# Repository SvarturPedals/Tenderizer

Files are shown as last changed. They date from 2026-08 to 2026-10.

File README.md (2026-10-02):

Tenderizer is a recreation of the Gristleizer Eurorack Module once produced by Endangered Audio Research.

-----------------------------------------------------------------------------------------------------------------------------

V1 prototype boards were ordered on 9-9-26. 

Tests were positive, but revealed a couple of small errors.

See links for testing and demo of V1 prototype:

https://www.youtube.com/watch?v=e3SwFMtvKbs

https://www.youtube.com/watch?v=fW0amLK4cTc

V2 prototypes ordered on 9-22-26 which included a prototype PCB material front panel.

V2 prototypes arrived on 9-29-26, Built and tested first unit with good results. 

Will distribute 3 board sets to select people to build and test during the months of October, November and December of 2026. 

Any issues found will be addressed in V3 Final version.

PXL_20260930_220714235~3PXL_20260930_211127180~2

10-1-26:

Updated Repository with BOM files. 

Excel and Open Office Calc files are identical

Markdown Table format

HTML format (https://html-preview.github.io/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)

-----------------------------------------------------------------------------------------------------------------------------

Current back of the envelope math for future Board Sets, Complete Kits, and a limited number of completed and tested modules

Board Sets : $25 USD

Complete kits : $85 USD

Built and Tested units with special front panels : $225 USD

Pricing subject to change, more details once launched.

I will set up an Etsy store front for the official launch.

Potential Launch date:

January 1, 2027

Once launched, all PCB fabrication files will be uploaded here along with a full build documentation and other project specific notes.

-----------------------------------------------------------------------------------------------------------------------------

Original Assembly document for E.A.R. Gristleizer Eurorack PCB

https://drive.google.com/file/d/1BdbNv-EVg8JeGNcPxPTs-spx8XBo5OCM/view?usp=sharing

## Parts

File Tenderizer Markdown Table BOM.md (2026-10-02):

| Components | Quantity | Value | Notes |
|---|---|---|---|
| Resistors | | | |
| R4 | 1 | 22R | 1/4w Metal Film Resistor 1% 2.5mmx6.8mm |
| R6,R11,R18,R32,R35 | 5 | 1K | 1/4w Metal Film Resistor 1% 2.5mmx6.8mm |
| R36 | 1 | 2.2K | 1/4w Metal Film Resistor 1% 2.5mmx6.8mm |
| R8 | 1 | 4.7K | 1/4w Metal Film Resistor 1% 2.5mmx6.8mm |
| R9,R14,R19,R24,R27,R31 | 6 | 10K | 1/4w Metal Film Resistor 1% 2.5mmx6.8mm |
| R13,R25 | 2 | 18K | 1/4w Metal Film Resistor 1% 2.5mmx6.8mm |
| R7 | 1 | 22K | 1/4w Metal Film Resistor 1% 2.5mmx6.8mm |
| R10,R26 | 2 | 27K | 1/4w Metal Film Resistor 1% 2.5mmx6.8mm |
| R16,R28 | 2 | 33K | 1/4w Metal Film Resistor 1% 2.5mmx6.8mm |
| R5,R34,R39 | 3 | 47K | 1/4w Metal Film Resistor 1% 2.5mmx6.8mm |
| R3,R33 | 2 | 56K | 1/4w Metal Film Resistor 1% 2.5mmx6.8mm |
| R22 | 1 | 82K | 1/4w Metal Film Resistor 1% 2.5mmx6.8mm |
| R15,R17,R20,R21 | 4 | 100K | 1/4w Metal Film Resistor 1% 2.5mmx6.8mm |
| R29 | 1 | 180K | 1/4w Metal Film Resistor 1% 2.5mmx6.8mm |
| R30 | 1 | 470K | 1/4w Metal Film Resistor 1% 2.5mmx6.8mm |
| R2,R12 | 2 | 1M | 1/4w Metal Film Resistor 1% 2.5mmx6.8mm |
| | | | |
| Capacitors | | | |
| C8 | 1 | 2.2nf | Polyester Box Film Body 2.5mm (minimum 25v DC Voltage Rating) |
| C7,C14 | 2 | 10nf | Polyester Box Film Body 2.5mm (minimum 25v DC Voltage Rating) |
| C2,C3 | 2 | 100nf | Polyester Box Film Body 2.5mm (minimum 25v DC Voltage Rating) |
| C1 | 1 | 470nf | Polyester Box Film Body 3.5mm (minimum 25v DC Voltage Rating) |
| C4 | 1 | 1uf | Aluminum Electrolytic 5mm diameter (minimum 25v DC Voltage Rating) |
| C5,C9 | 2 | 10uf | Aluminum Electrolytic 5mm diameter (minimum 25v DC Voltage Rating) |
| C11,C12 | 2 | 100uf | Aluminum Electrolytic 6.3mm diameter (minimum 25v DC Voltage Rating) |
| | | | |
| Diodes | | | |
| D2 | 1 | 1N4738  | Zener Diode |
| D3,D4 | 2 | 1N4148  | Switching Signal Diode |
| D6,D7 | 2 | 1N5817  | Diode Schottky |
| D9 | 1 | 5mm LED | Red Diffused or color of your choice |
| | | | |
| Transistors | | | |
| Q1 | 1 | BF256 | Board sets and Kits ordered from Svartur Effects will include this part |
| Q3,Q4 | 2 | 2N3906  | |
| | | | |
| Integrated Circuits | | | |
| U1,U2,U3 | 3 | RC4558  | DIP Package |
| | | | |
| Other | | | |
| DPDT On/On toggle switch | 2 | | |
| Bias, Depth, Level, Gain, Filter | 5 | B100k | |
| Frequency | 1 | A10k | |
| 3.5mm jacks | 10 | | Thonk PJ301-M Style |
| 1x16 2.54mm Male Pin Connector | 1 | | |
| 1x16 2.54mm Female Pin Connector | 1 | | |
| 1x8 2.54mm Male Pin Connector | 1 | | |
| 1x8 Female Pin Connector | 1 | | |
| 2x5 Eurorack Power Connector | 1 | | |
| 8 Pin IC Socket | 3 | | |
| 3 Pin Transistor Socket (Optional) | 3 | | |

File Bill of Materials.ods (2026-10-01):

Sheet: Master BOM List
Components | Quantity | Value | Notes
Resistors
R4 | 1 | 22R | 1/4w Metal Film Resistor 1% 2.5mmx6.8mm
R6,R11,R18,R32,R35 | 5 | 1K | 1/4w Metal Film Resistor 1% 2.5mmx6.8mm
R36 | 1 | 2.2K | 1/4w Metal Film Resistor 1% 2.5mmx6.8mm
R8 | 1 | 4.7K | 1/4w Metal Film Resistor 1% 2.5mmx6.8mm
R9,R14,R19,R24,R27,R31 | 6 | 10K | 1/4w Metal Film Resistor 1% 2.5mmx6.8mm
R13,R25 | 2 | 18K | 1/4w Metal Film Resistor 1% 2.5mmx6.8mm
R7 | 1 | 22K | 1/4w Metal Film Resistor 1% 2.5mmx6.8mm
R10,R26 | 2 | 27K | 1/4w Metal Film Resistor 1% 2.5mmx6.8mm
R16,R28 | 2 | 33K | 1/4w Metal Film Resistor 1% 2.5mmx6.8mm
R5,R34,R39 | 3 | 47K | 1/4w Metal Film Resistor 1% 2.5mmx6.8mm
R3,R33 | 2 | 56K | 1/4w Metal Film Resistor 1% 2.5mmx6.8mm
R22 | 1 | 82K | 1/4w Metal Film Resistor 1% 2.5mmx6.8mm
R15,R17,R20,R21 | 4 | 100K | 1/4w Metal Film Resistor 1% 2.5mmx6.8mm
R29 | 1 | 180K | 1/4w Metal Film Resistor 1% 2.5mmx6.8mm
R30 | 1 | 470K | 1/4w Metal Film Resistor 1% 2.5mmx6.8mm
R2,R12 | 2 | 1M | 1/4w Metal Film Resistor 1% 2.5mmx6.8mm
Capacitors
C8 | 1 | 2.2nf | Polyester Box Film 5mm Lead Spacing Body Thickness 2.5mm (minimum 25v DC Voltage Rating)
C7,C14 | 2 | 10nf | Polyester Box Film 5mm Lead Spacing Body Thickness 2.5mm (minimum 25v DC Voltage Rating)
C2,C3 | 2 | 100nf | Polyester Box Film 5mm Lead Spacing Body Thickness 2.5mm (minimum 25v DC Voltage Rating)
C1 | 1 | 470nf | Polyester Box Film 5mm Lead Spacing Body Thickness 3.5mm (minimum 25v DC Voltage Rating)
C4 | 1 | 1uf | Aluminum Electrolytic 5mm diameter (minimum 25v DC Voltage Rating)
C5,C9 | 2 | 10uf | Aluminum Electrolytic 5mm diameter (minimum 25v DC Voltage Rating)
C11,C12 | 2 | 100uf | Aluminum Electrolytic 5mm diameter (minimum 25v DC Voltage Rating)
Diodes
D2 | 1 | 1N4738 | ZENER DIODE 1W 8.2V
D3,D4 | 2 | 1N4148 | Switching Signal Diode
D6,D7 | 2 | 1N5817 | Diode Schottky 1A 20V
D9 | 1 | 5mm LED | Red Diffused or color of your choice
Transistors
Q1 | 1 | BF256 | TO-92 Package (Board sets ordered from Svartur Effects will include this part)
Q3,Q4 | 2 | 2N3906 | TO-92 Package
Integrated Circuits
U1,U2,U3 | 3 | RC4558 | DIP Package
Other
DPDT On/On toggle switch | 2
Bias, Depth, Level, Gain, Filter | 5 | B100k
Frequency | 1 | A10k
3.5mm jacks | 10 |  | Thonk PJ301-M Style
1x16 2.54mm Male Pin Connector | 1 |  | Just get a few strips of the 40 pin breakable headers at the link ---->
1x16 2.54mm Female Pin Connector | 1
1x8 2.54mm Male Pin Connector | 1 |  | Just get a few strips of the 40 pin breakable headers at the link ---->
1x8 Female Pin Connector | 1
2x5 Eurorack Power Connector | 1
8 Pin IC Socket | 3
3 Pin Transistor Socket (Optional) | 3

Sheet: US Domestic Ordering
Components | Quantity | Value | Mouser Part Number | Quantity | Supplier Links
Resistors
R4 | 1 | 22R | 660-MF1/4LCT52R220J 1 | Mouser BOM Order Tool
R6,R11,R18,R32,R35 | 5 | 1K | 660-MF1/4LCT52R102J 5 | For quick entry, log in to you Mouser Account and navigate to the BOM tool at https://www.mouser.com/en/account/boms
R36 | 1 | 2.2K | 660-MF1/4LCT52R222G 1 | Select “Create New BOM” then “Copy and Paste”
R8 | 1 | 4.7K | 660-MF1/4LCT52R472J 1 | In this Spreadsheet, select Cell D3, hold Shift, then select Cell D53. With Cells D3 through D53 highlighted, right click and select “Copy” or hit Ctrl C
R9,R14,R19,R24,R27,R31 | 6 | 10K | 660-MF1/4DCT52R1002F 6 | Paste that list into the BOM window on Mouser then select “Import My Data”
R13,R25 | 2 | 18K | 660-MF1/4DCT52R1802F 2 | Once the BOM is successfully imported, select Next and then “Process BOM”
R7 | 1 | 22K | 660-MF1/4DCT52R2202F 1 | Once the BOM is processed, select “Select All” and then “Buy Selected Items” to move the items to your cart.
R10,R26 | 2 | 27K | 660-MF1/4DCT52R2702F 2
R16,R28 | 2 | 33K | 660-MF1/4DCT52R3302F 2 | If you wish to purchase components for more than one Tenderizer build, you can input your multiplier in the window beside the ‘Buy Selected Items” button.
R5,R34,R39 | 3 | 47K | 660-MF1/4DCT52R4702F 3 | I always suggest purchasing a few extra components, especially resistors, capacitors, diodes and transistors as a general rule of thumb.
R3,R33 | 2 | 56K | 660-MF1/4DCT52R5602F 2 | The cost of a few extra components is usually very minimal and helps you to build a stock of components for future builds or have spares should an issue arise such as faulty components or damaged components.
R22 | 1 | 82K | 660-MF1/4DCT52R8202F 1
R15,R17,R20,R21 | 4 | 100K | 660-MF1/4D52R1003F 4
R29 | 1 | 180K | 660-MF1/4DCT52R1803F 1
R30 | 1 | 470K | 660-MF1/4DCT52R4703F 1
R2,R12 | 2 | 1M | 660-MF1/4DCT52A1004F 2
Capacitors
C8 | 1 | 2.2nf | 80-SMR5222J50J0116 1
C7,C14 | 2 | 10nf | 80-MMK5103K63J01TR18 2
C2,C3 | 2 | 100nf | 80-R82DC3100AA50J 2
C1 | 1 | 470nf | 80-R82DC3470SH60J 1
C4 | 1 | 1uf | 710-860020672005 1
C5,C9 | 2 | 10uf | 710-860010572002 2
C11,C12 | 2 | 100uf | 710-860010573007 2
Diodes
D2 | 1 | 1N4738 | 512-1N4738A 1
D3,D4 | 2 | 1N4148 | 512-1N4148 2
D6,D7 | 2 | 1N5817 | 833-1N5817-TP 2
D9 | 1 | 5mm LED |  | https://synthcube.com/led-5mm-diffused-red-yellow-green-or-blue/
Transistors
Q1 | 1 | BF256 |  | A BF256B transistor will be included with every Board Set and Complete Kit if ordered from Svartur Effects or order from https://www.newark.com/onsemi/bf256b/transistor-jfet-n-ch-30v-to-92/dp/31Y0551
Q3,Q4 | 2 | 2N3906 | 512-2N3906TF 2
Integrated Circuits
U1,U2,U3 | 3 | RC4558 | 595-RC4558P 3
Other
DPDT On/On toggle switch | 2 |  |  | https://stompboxparts.com/switches/dpdt-toggle-switch-on-on-solder-lug-short-bat/ https://synthcube.com/dpdt-on-on-short-lever-pc-mount/
Bias, Depth, Level, Gain, Filter | 5 | B100k |  | https://synthcube.com/9mm-vertical-pc-mount-6-35mm-round-shaft/
Frequency | 1 | A10k |  | https://synthcube.com/9mm-vertical-pc-mount-6-35mm-round-shaft/
3.5mm jacks | 10 |  |  | https://synthcube.com/3-5mm-mono-and-stereo-audio-jacks/ 3.5mm stereo jack, WQP419GR (PJ366ST) (green jacks) Be Sure to order Nuts as well: https://synthcube.com/round-knurled-nut-zinc-3-5mm-audio-jack-qp/
1x16 2.54mm Male Pin Connector | 1 |  | 710-61301611121 1
1x16 2.54mm Female Pin Connector | 1 |  | 710-61301611821 1
1x8 2.54mm Male Pin Connector | 1 |  | 710-61300811121 1
1x8 Female Pin Connector | 1 |  | 737-RS1-08-G 1
2x5 Eurorack Power Connector | 1 |  | 538-70246-1001 1
8 Pin IC Socket | 3 |  | 571-2485264-1 3
3 pin Transistor Socket (Optional) | 3 |  | 737-SMC-1-03-1-GT 3

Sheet: Tayda Order Links
Components | Quantity | Value | Supplier Links
Resistors
R4 | 1 | 22R | https://www.taydaelectronics.com/resistors/1-4w-metal-film-resistors/test-group-2.html
R6,R11,R18,R32,R35 | 5 | 1K | https://www.taydaelectronics.com/resistors/1-4w-metal-film-resistors/test-group-2.html
R36 | 1 | 2.2K | https://www.taydaelectronics.com/resistors/1-4w-metal-film-resistors/test-group-2.html
R8 | 1 | 4.7K | https://www.taydaelectronics.com/resistors/1-4w-metal-film-resistors/test-group-2.html
R9,R14,R19,R24,R27,R31 | 6 | 10K | https://www.taydaelectronics.com/resistors/1-4w-metal-film-resistors/test-group-2.html
R13,R25 | 2 | 18K | https://www.taydaelectronics.com/resistors/1-4w-metal-film-resistors/test-group-2.html
R7 | 1 | 22K | https://www.taydaelectronics.com/resistors/1-4w-metal-film-resistors/test-group-2.html
R10,R26 | 2 | 27K | https://www.taydaelectronics.com/resistors/1-4w-metal-film-resistors/test-group-2.html
R16,R28 | 2 | 33K | https://www.taydaelectronics.com/resistors/1-4w-metal-film-resistors/test-group-2.html
R5,R34,R39 | 3 | 47K | https://www.taydaelectronics.com/resistors/1-4w-metal-film-resistors/test-group-2.html
R3,R33 | 2 | 56K | https://www.taydaelectronics.com/resistors/1-4w-metal-film-resistors/test-group-2.html
R22 | 1 | 82K | https://www.taydaelectronics.com/resistors/1-4w-metal-film-resistors/test-group-2.html
R15,R17,R20,R21 | 4 | 100K | https://www.taydaelectronics.com/resistors/1-4w-metal-film-resistors/test-group-2.html
R29 | 1 | 180K | https://www.taydaelectronics.com/resistors/1-4w-metal-film-resistors/test-group-2.html
R30 | 1 | 470K | https://www.taydaelectronics.com/resistors/1-4w-metal-film-resistors/test-group-2.html
R2,R12 | 2 | 1M | https://www.taydaelectronics.com/resistors/1-4w-metal-film-resistors/test-group-2.html
Capacitors
C8 | 1 | 2.2nf | https://www.taydaelectronics.com/capacitors/polyester-film-box-type-capacitors/2-2nf-2200pf-100v-5-polyester-film-box-type-capacitor-kemet.html
C7,C14 | 2 | 10nf | https://www.taydaelectronics.com/capacitors/polyester-film-box-type-capacitors/0-01uf-100v-5-kemet-polyester-film-box-type-capacitor-ammo.html
C2,C3 | 2 | 100nf | https://www.taydaelectronics.com/0-1uf-100v-5-kemet-polyester-film-box-type-capacitor.html
C1 | 1 | 470nf | https://www.taydaelectronics.com/0-47-uf-63v-5-kemet-polyester-film-box-type-capacitor.html
C4 | 1 | 1uf | https://www.taydaelectronics.com/capacitors/electrolytic-capacitors/nichicon-1uf-50v-105c-radial-electrolytic-capacitor-5-11mm.html
C5,C9 | 2 | 10uf | https://www.taydaelectronics.com/capacitors/electrolytic-capacitors/10uf-50v-105c-aluminum-radial-electrolytic-capacitor-nhg.html
C11,C12 | 2 | 100uf | https://www.taydaelectronics.com/capacitors/electrolytic-capacitors/100uf-35v-105c-jrb-radial-electrolytic-capacitor-6x12mm.html
Diodes
D2 | 1 | 1N4738 | https://www.taydaelectronics.com/1n4738-zener-diode-1w-8-2v.html
D3,D4 | 2 | 1N4148 | https://www.taydaelectronics.com/1n4148-switching-signal-diode.html
D6,D7 | 2 | 1N5817 | https://www.taydaelectronics.com/1n5817-diode-schottky-1a-20v.html
D9 | 1 | 5mm LED
Transistors
Q1 | 1 | BF256 | A BF256B transistor will be included with every Board Set and Complete Kit if ordered from Svartur Effects or order from https://www.newark.com/onsemi/bf256b/transistor-jfet-n-ch-30v-to-92/dp/31Y0551
Q3,Q4 | 2 | 2N3906 | https://www.taydaelectronics.com/2n3906-general-propose-pnp-transistor.html
Integrated Circuits
U1,U2,U3 | 3 | RC4558 | https://www.taydaelectronics.com/njm4558d-njm4558-4558-ic-dual-op-amp.html
Other
DPDT On/On toggle switch | 2 |  | https://www.taydaelectronics.com/electromechanical/switches-key-pad/toggle-switch/mini-toggle-switch-1m-series-dpdt-on-on.html
Bias, Depth, Level, Gain, Filter | 5 | B100k | https://www.taydaelectronics.com/potentiometer-variable-resistors/rotary-potentiometer/linear/tayda-100k-ohm-linear-taper-potentiometer-round-shaft-pcb-9mm-6-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
Frequency | 1 | A10k | https://www.taydaelectronics.com/potentiometer-variable-resistors/rotary-potentiometer/logarithmic/10k-ohm-logarithmic-taper-potentiometer-round-shaft-pcb-9mm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
3.5mm jacks | 10 |  | https://www.taydaelectronics.com/sale/pj-3001f-3-5-mm-mono-phone-jack.html
1x16 2.54mm Male Pin Connector | 1 |  | https://www.taydaelectronics.com/connectors-sockets/pin-headers/40-pin-male-2-54-mm-single-row-pin-header-break-away-round-pin-gold-plated.html
1x16 2.54mm Female Pin Connector | 1 |  | https://www.taydaelectronics.com/16-pin-2-54-mm-single-row-female-pin-header.html
1x8 2.54mm Male Pin Connector | 1 |  | https://www.taydaelectronics.com/connectors-sockets/pin-headers/40-pin-male-2-54-mm-single-row-pin-header-break-away-round-pin-gold-plated.html
1x8 Female Pin Connector | 1 |  | https://www.taydaelectronics.com/8-pin-2-54-mm-single-row-female-pin-header.html
2x5 Eurorack Power Connector | 1 |  | https://www.taydaelectronics.com/10-pin-box-header-connector-2-54mm.html
8 Pin IC Socket | 3 |  | https://www.taydaelectronics.com/8-pin-dip-ic-socket-machine-tooled.html
3 Pin Transistor Socket (Optional) | 3 |  | https://www.taydaelectronics.com/connectors-sockets/sockets/3-pin-dip-sip-ic-sockets-adaptor-solder-type-single-row.html

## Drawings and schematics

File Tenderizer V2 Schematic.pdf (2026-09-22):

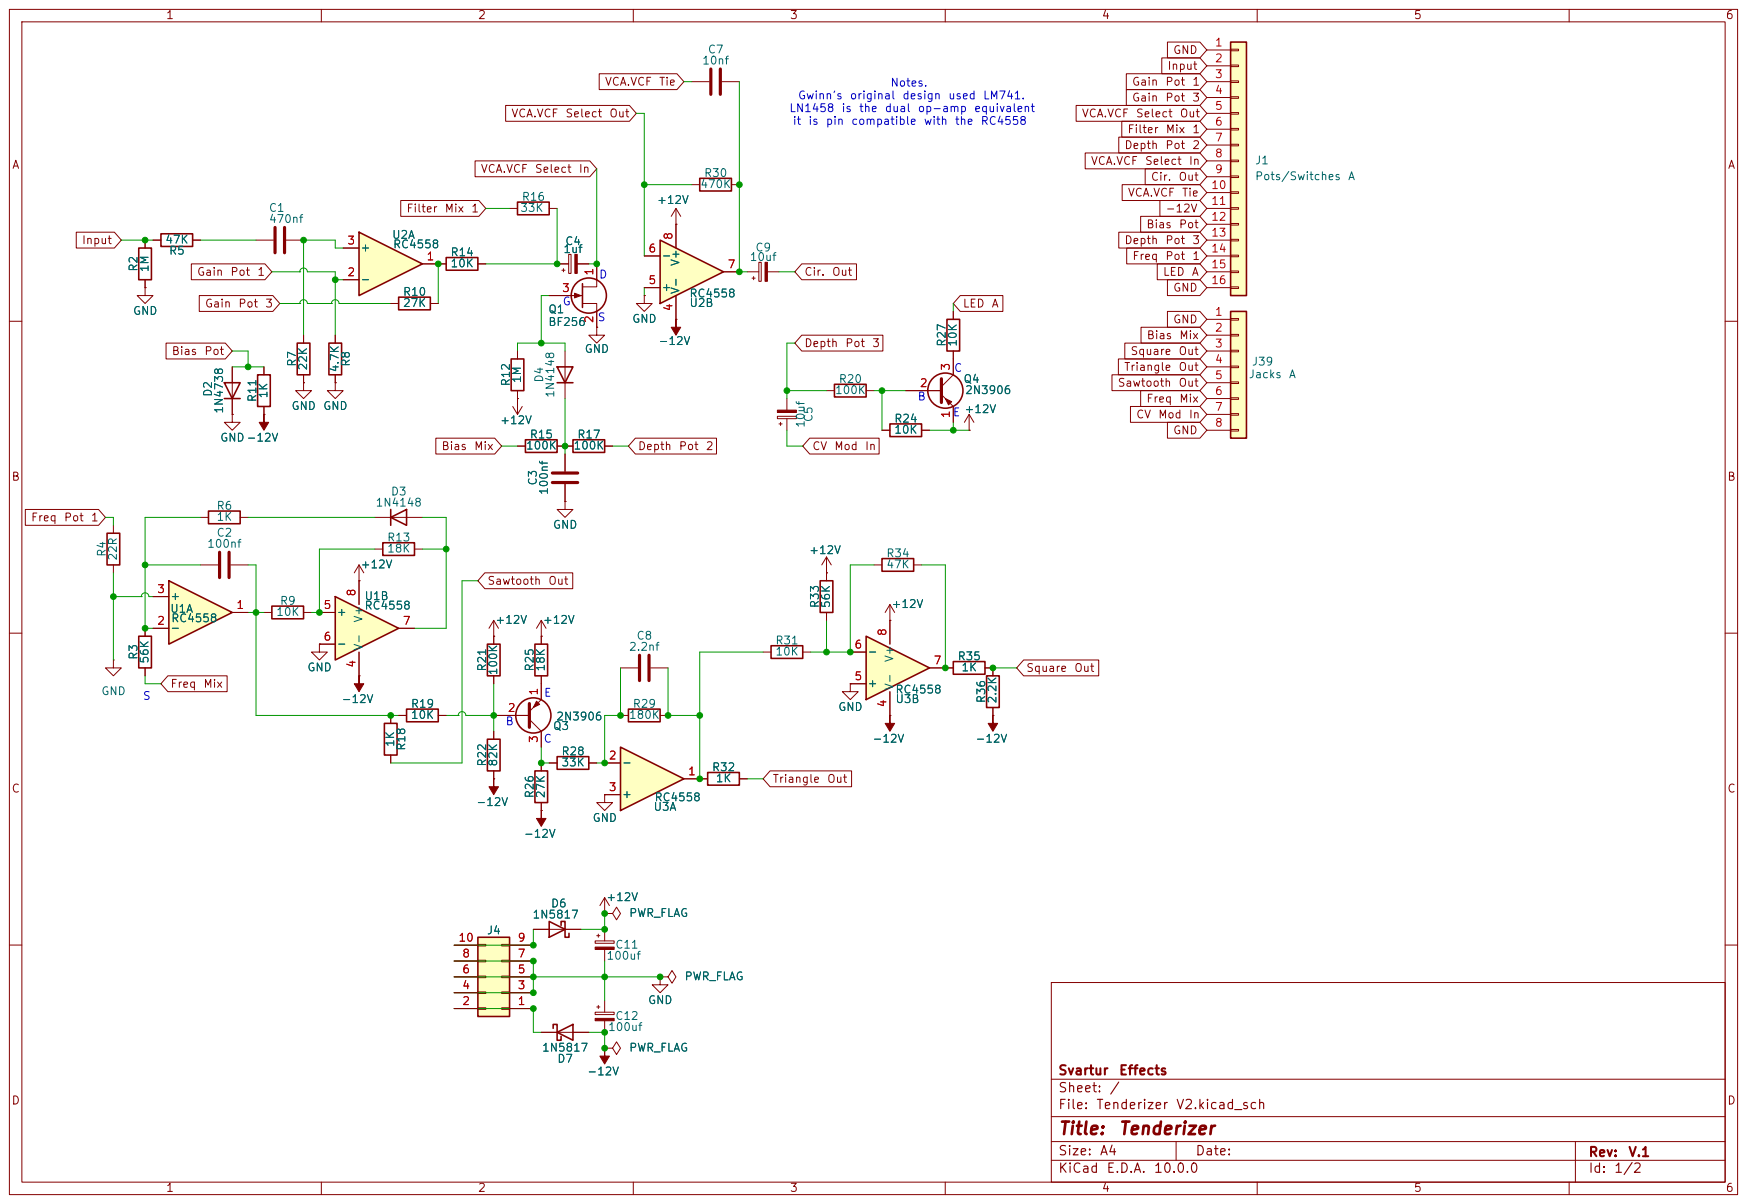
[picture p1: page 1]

Notes. Gwinn's original design used LM741. LN1458 is the dual op-amp equivalent

VCA.VCF Select Out Depth Pot 2 Cir. Out VCA.VCF Tie

it is pin compatible with the RC4558 G

Freq Mix Gain Pot 1

VCA.VCF Select In D

Triangle Out Sawtooth Out Square Out GND

Size: A4 | Rev: V.1
KiCad E.D.A. 10.0.0 | Id: 1/2

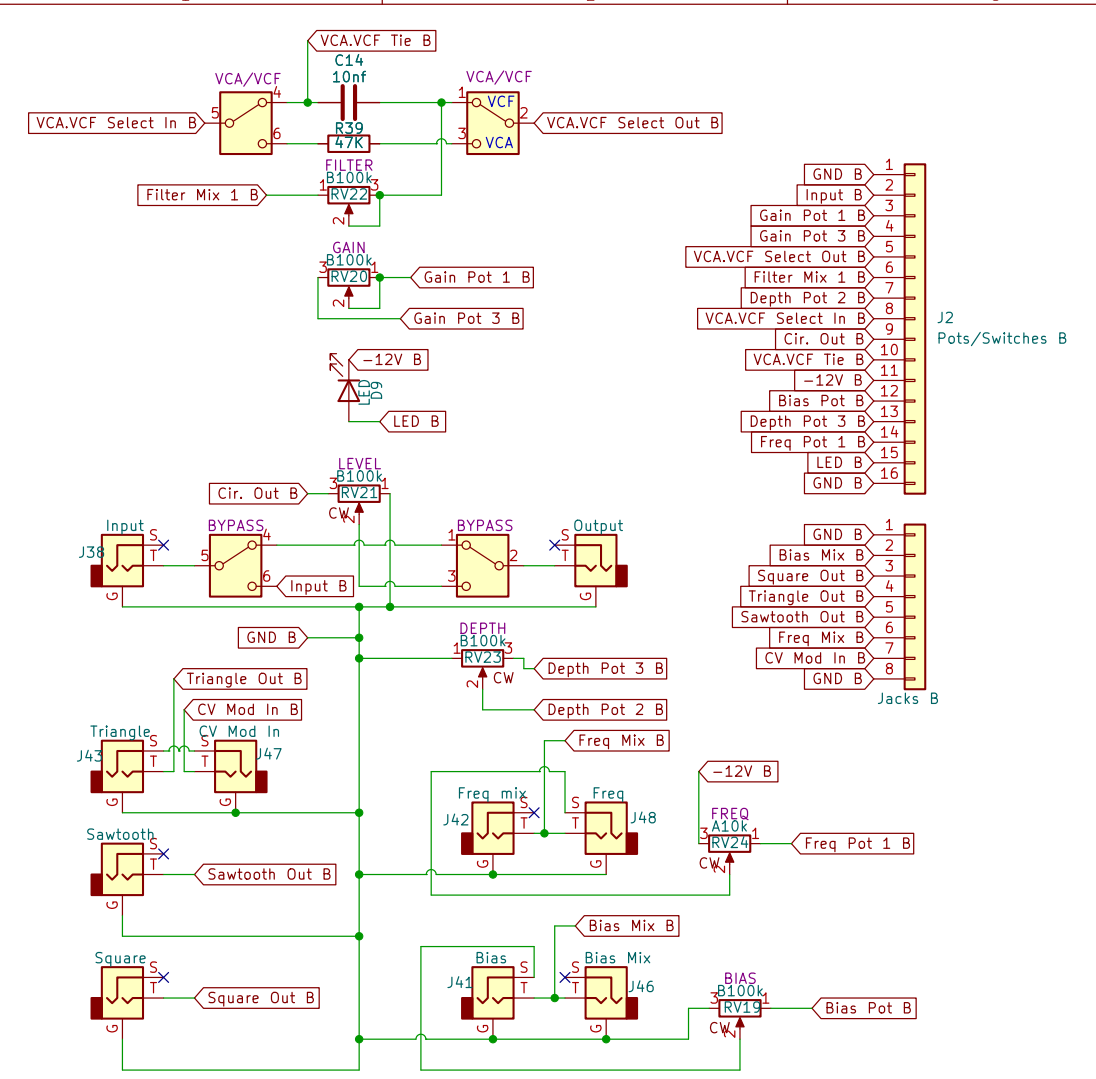
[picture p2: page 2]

VCA.VCF Select Out B

VCA.VCF Select In B

Size: A4 | Rev: V.1
KiCad E.D.A. 10.0.0 | Id: 2/2

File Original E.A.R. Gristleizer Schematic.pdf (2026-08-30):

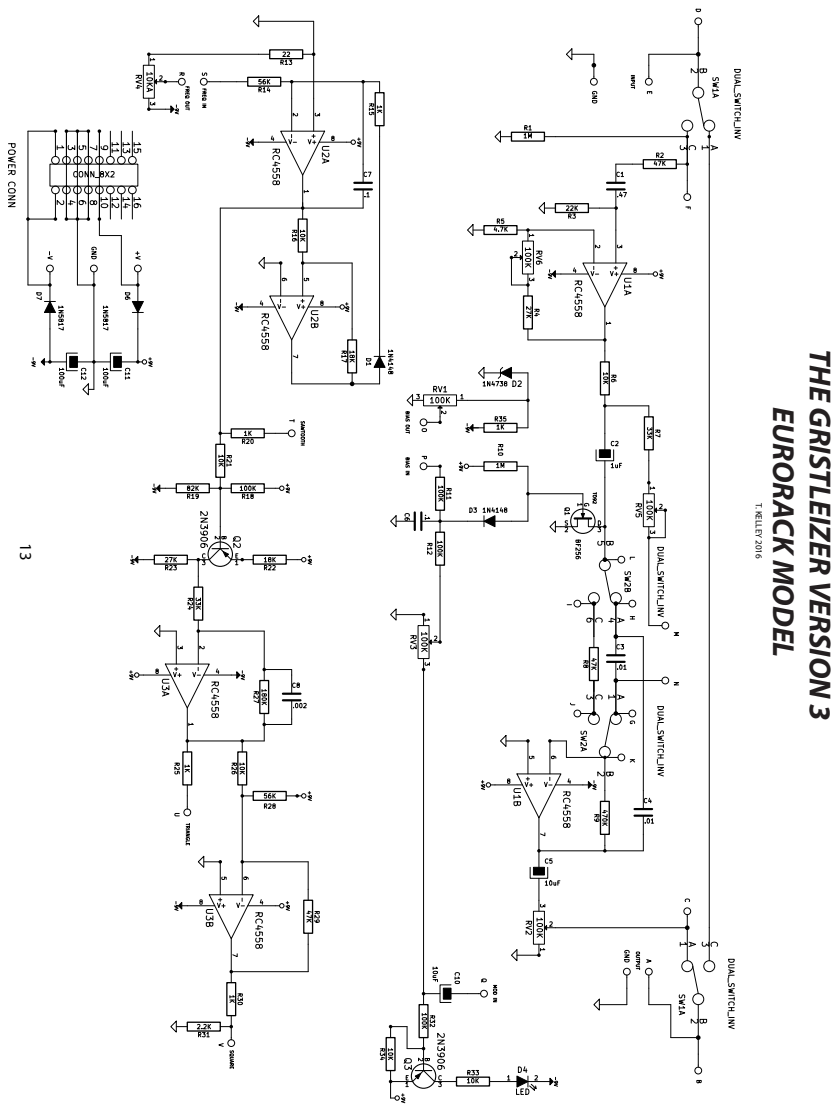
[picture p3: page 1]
EURORACK MODEL; T. KELLEY 2016

THE GRISTLEIZER VERSION 3

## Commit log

2026-08-30 Add files via upload
    Upload of Tenderizer KiCad Project files.
    Current as of 8-30-26.
    [Tenderizer V1.kicad_pcb, Tenderizer V1.kicad_sch, control_board.kicad_sch]
2026-08-30 Add files via upload
    Original EAR schematic
2026-08-31 Upload of revised schematic and board layout
    Revised board and schematic pursuant to 3rd party reviewer's notes.
    Board and Schematic V1 finalized 8-31-26 @ 5:00pm
    [Tenderizer V1.kicad_pcb, Tenderizer V1.kicad_sch, control_board.kicad_sch]
2026-09-22 Rename Schematic.pdf to Original E.A.R. Gristleizer Schematic.pdf
2026-09-22 Rename Tenderizer V2.pdf to Tenderizer V2 Schematic.pdf
2026-10-01 Create Tenderizer V2 Prototype Photos (unsorted)
2026-10-01 Create BOM Github Markdown Format
2026-10-01 Update BOM Github Markdown Format
2026-10-01 Create Tenderizer BOM Markdown
2026-10-01 Update Tenderizer BOM Markdown
2026-10-01 Create Tenderizer HTML BOM File
2026-10-02 Rename test.md to Tenderizer Markdown Table BOM.md
